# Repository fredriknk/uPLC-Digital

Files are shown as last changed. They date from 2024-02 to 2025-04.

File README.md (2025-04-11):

# μPLC-Digital
### Pcbway Sponsorship
Thanks so much to [PCBWay](https://www.pcbway.com/) who offered to assemble my first prototype batch of all three [uPLC modules](https://github.com/fredriknk/uPLC-stack). They deliver awesome quality as always, see the result for yourself below.

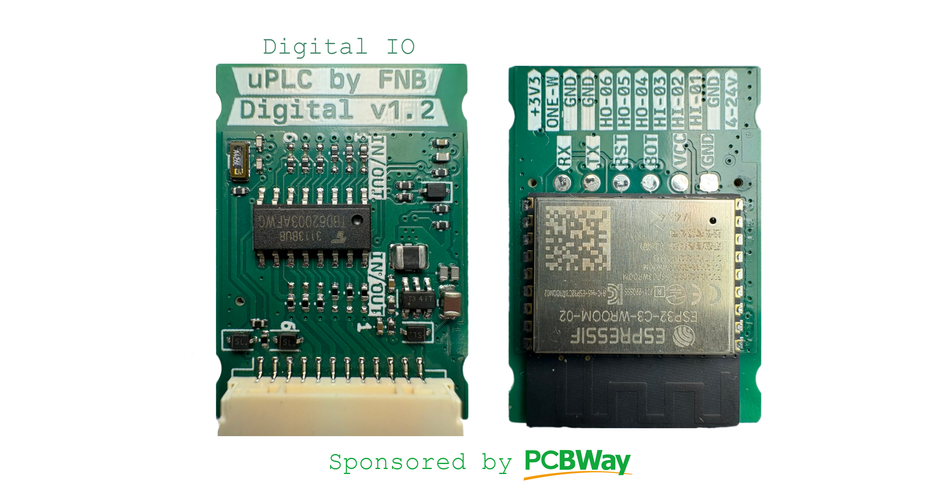
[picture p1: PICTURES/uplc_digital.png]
Front


 I now have two prototypes of the uPLC-Digital so ESP-Home integrations will come soon.

ESP micro PLC the size of a post stamp. 

The uPLC-digital version is an [ESP-32-C3](./DOCUMENTATION/esp-12f_product_specification_en.pdf) wifi, bluetooth module for communication and MCU, it has a 3.8-24V buck regulator, has three 2.5-25V inputs, three 2.5-25v 100ma high speed open drain outputs through a [TBD062003](./DOCUMENTATION/Transistor-array-2304140030_TOSHIBA-TBD62003AFWG_C114084.pdf) DMOS transistor array ic. And one protected 3.3v GPIO for onwire communication (Eg for DS18b20 sensors). The digital version allso has input voltage monitoring for battery applications. 

The HO HI ports can be configured to be inputs or outputs by jumping solder bridges one each side of the IC. By default 1-3 are outputs and 4-6 are inputs. 

[Schematic](./DOCUMENTATION/_schematic.pdf)

[Assembly IBOM](https://htmlpreview.github.io/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)

## Specifications
| **Parameter** | **Description** |
|---|---|
| _Input voltage_ | 3.8-24v |
| _Current_ | TBD Wifi: ##mA, Radio Off: ##mA, Deep sleep ##uA |  
| _Communication_ | 2.4ghz WIFI, Uart TTL |
| _Baudrate_ | 115200 |
| _PCB size_ | 21x31.4mm |
| _PCB info_ | 1.6mm FR4, HASL lead free, 4 layer |
| _Case size_ | XxXxXmm TBD |

## FIRST PRODUCTION PROTOTYPE
TODO

## Connector

| **Label** | **GPIO**|**Description** |
|---|-----|---|
|_3V3_ | 3V3 | 3.3v output for sensor connection |
|_ONE-W_ | GPIO18  | Protected gpio for onewire comm |
|_GND_ | GND | GND port for sensor connection|
|_GND_ | GND | GND port for sensor connection |
|_HO-06_ | GPIO10  | 25v 100ma open drain output |
|_HO-05_ | GPIO19  | 25v 100ma open drain output |
|_HO-04_ | GPIO3  | 25v 100ma open drain output |
|_HI-03_ | GPIO7  | 2.5-25v input (with pulldown) |
|_HI-02_ | GPIO6  | 2.5-25v input (with pulldown) |
|_HI-01_ | GPIO5  | 2.5-25v input (with pulldown) |
|_GND_ | GND |  Ground  |
|_4-24V_ | Buck reg |3.8-24v polarity protected input |

## PCB Pictures
PCB assembly by [PCBWay](https://www.pcbway.com/)
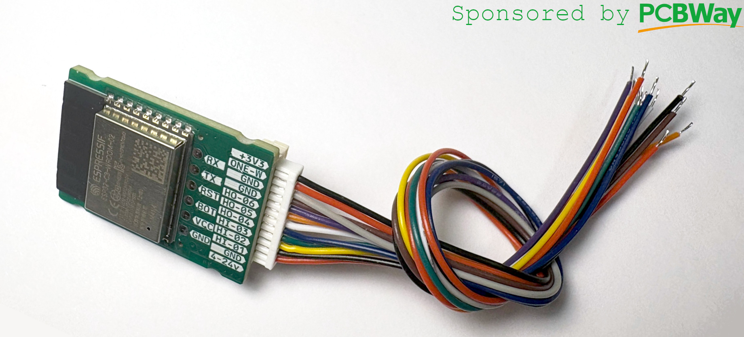
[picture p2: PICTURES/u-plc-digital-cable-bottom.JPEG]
Cable1

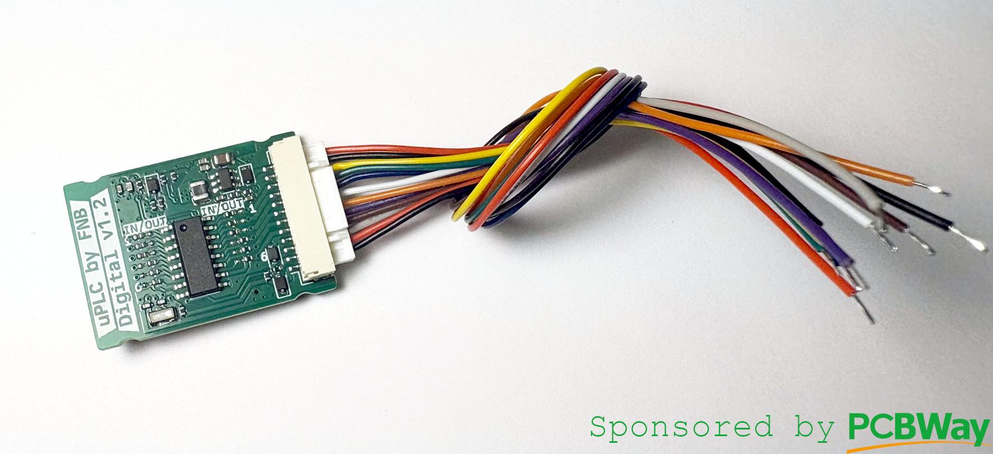
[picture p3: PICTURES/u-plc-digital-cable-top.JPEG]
Cable2

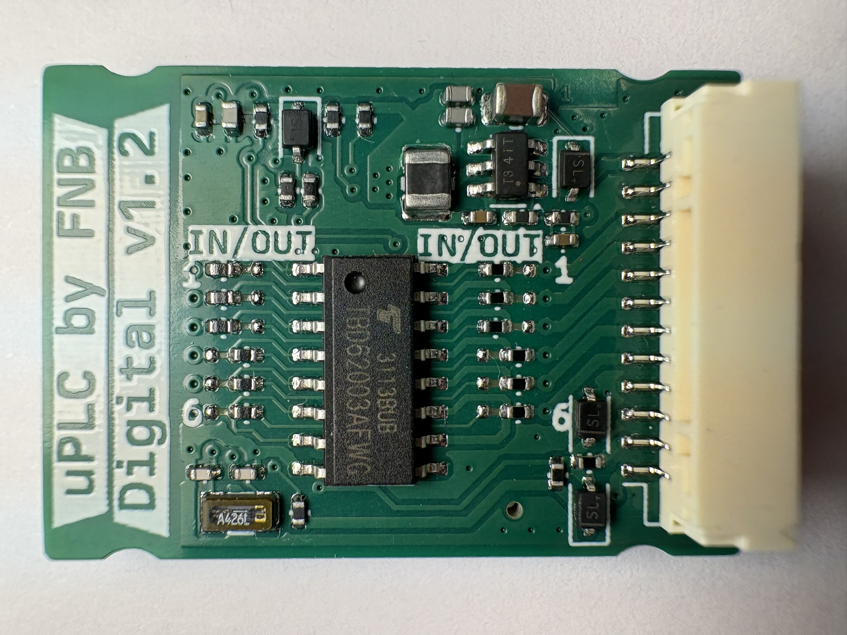
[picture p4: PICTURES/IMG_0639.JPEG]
Top

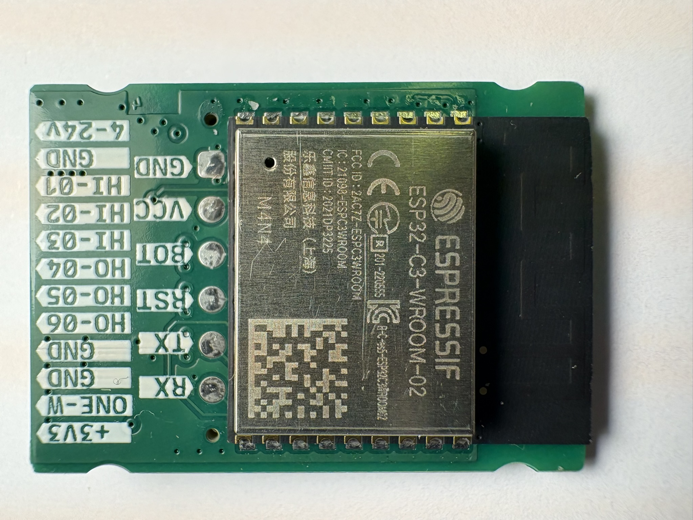
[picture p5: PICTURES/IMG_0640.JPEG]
Bottom


## Homeassistant Implementation
TODO

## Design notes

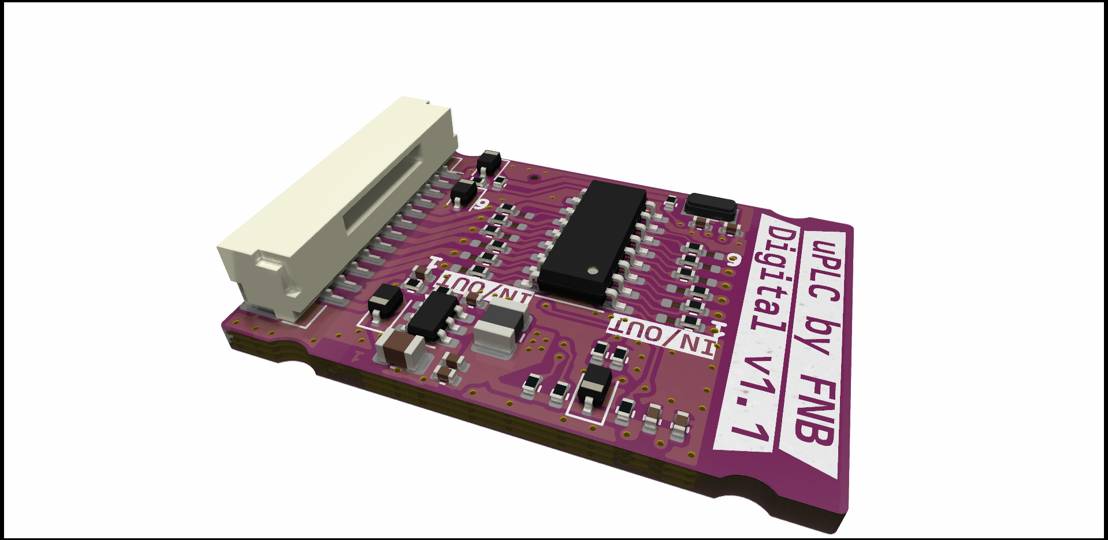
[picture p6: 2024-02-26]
PICTURES/TOP.PNG

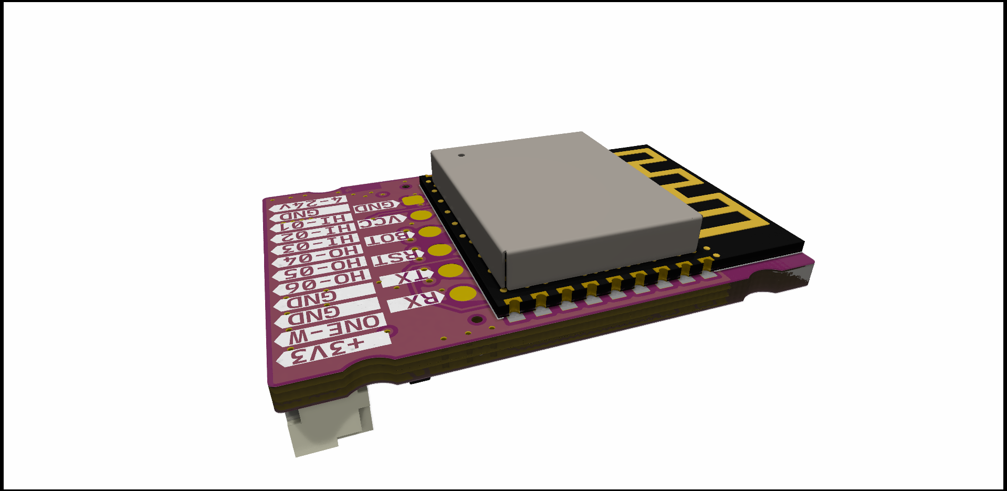
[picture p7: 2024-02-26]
PICTURES/BOTTOM.PNG

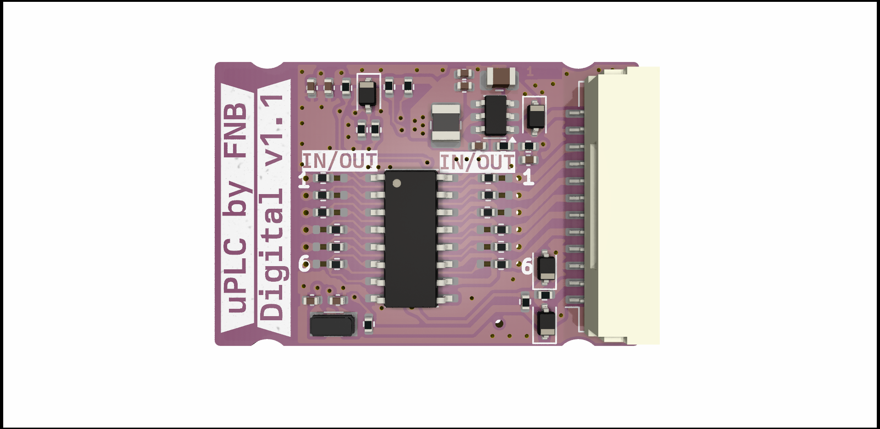
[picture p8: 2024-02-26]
PICTURES/OTOP.PNG

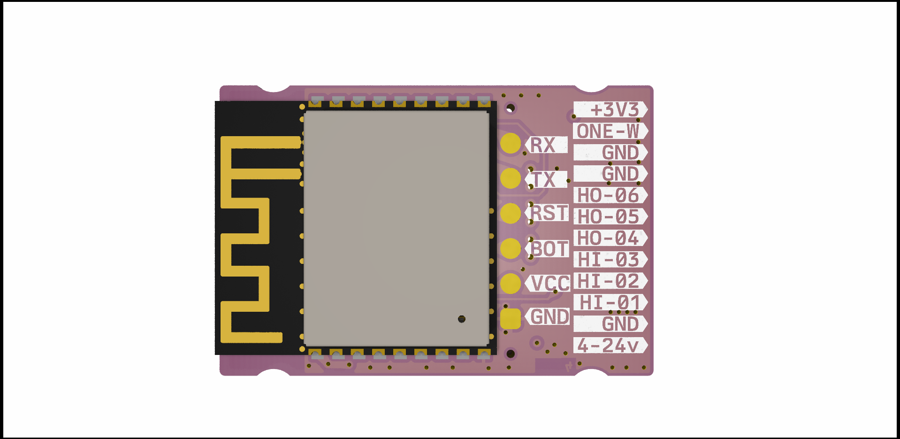
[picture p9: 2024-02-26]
PICTURES/OBOT.PNG

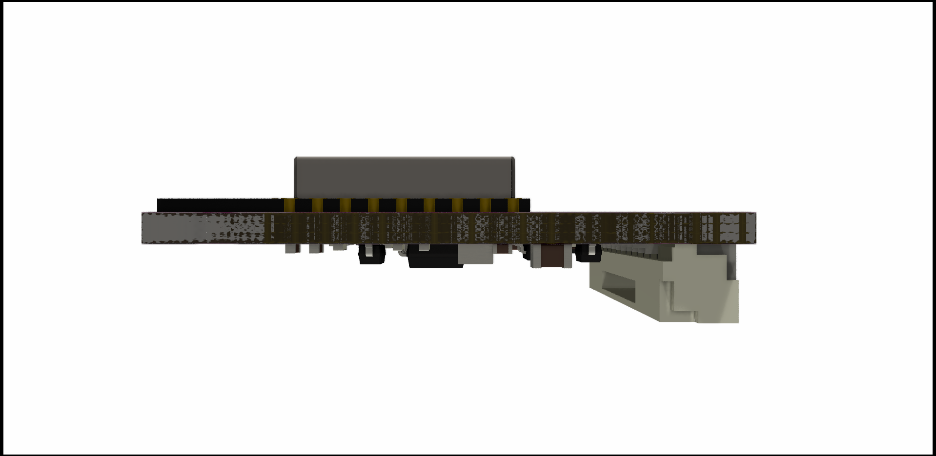
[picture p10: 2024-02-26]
PICTURES/OLEFT.png

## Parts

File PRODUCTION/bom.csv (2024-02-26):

Designator | Footprint | Quantity | Value | LCSC Part #
C1, C4 | 0402 | 2 | 20pf | C1554
C11, C12, C8 | 0402 | 3 | 22uf | C415703
C2, C3, C9 | 0402 | 3 | 0.1uF | C307331
C5 | 0805 | 1 | 10uF | C162422
D1, D2, D3, D4 | D_SOD-323 | 4 | 1N5819WS | C191023
J1 | TestPoint_Pad_1.0x1.0mm_6pad | 1 | Conn_01x06_Pin | DNP
J2 | JST_GH_SM12B-GHS-TB_1x12-1MP_P1.25mm_Horizontal | 1 | SM12B-GHS-TB(LF)(SN) | C265421
JP1, JP10, JP11, JP12, JP2, JP3, JP4, JP5, JP6, JP7, JP8, JP9 | SolderJumper-3_P1.3mm_BridgedSMD12_0402 | 12 | 0R
L1 | 1008 | 1 | 6.8uH | C98340
R1, R2, R3, R4, R5, R6 | 0402 | 6 | 10K | C25744
R13 | 0402 | 1 | 100R | C25076
R14 | 0402 | 1 | 182k | C11481
R15 | 0402 | 1 | 62k | C137950
R7 | 0402 | 1 | 309k
U1 | TSOT-23-6 | 1 | AP63201WU | C2071044
U2 | SOIC-16_3.9x9.9mm_P1.27mm | 1 | TBD62003AFWG | C114084
U3 | ESP32-C3-WROOM-02 | 1 | ESP32-C3-WROOM-02 | C2934560
Y1 | Crystal_SMD_3215-2Pin_3.2x1.5mm | 1 | 32.768khz 3215 12.5pf | C32346

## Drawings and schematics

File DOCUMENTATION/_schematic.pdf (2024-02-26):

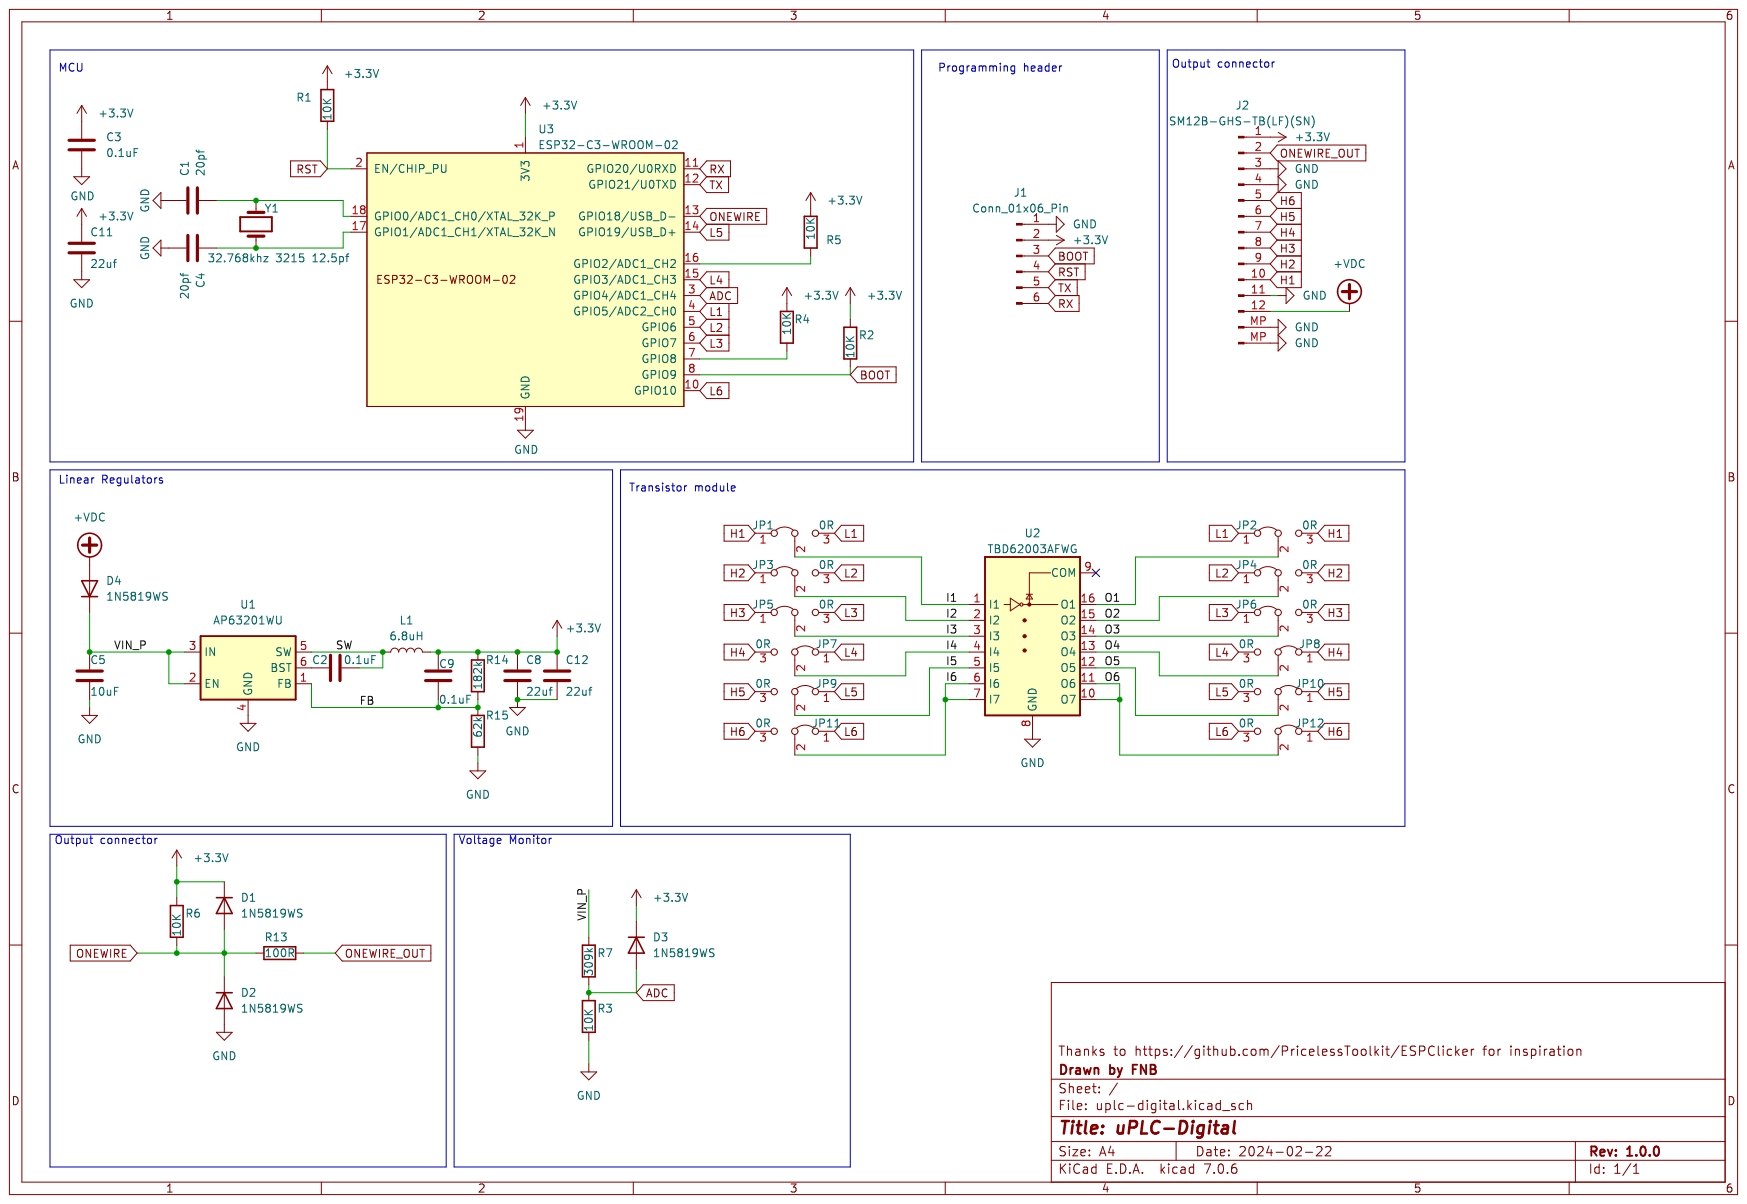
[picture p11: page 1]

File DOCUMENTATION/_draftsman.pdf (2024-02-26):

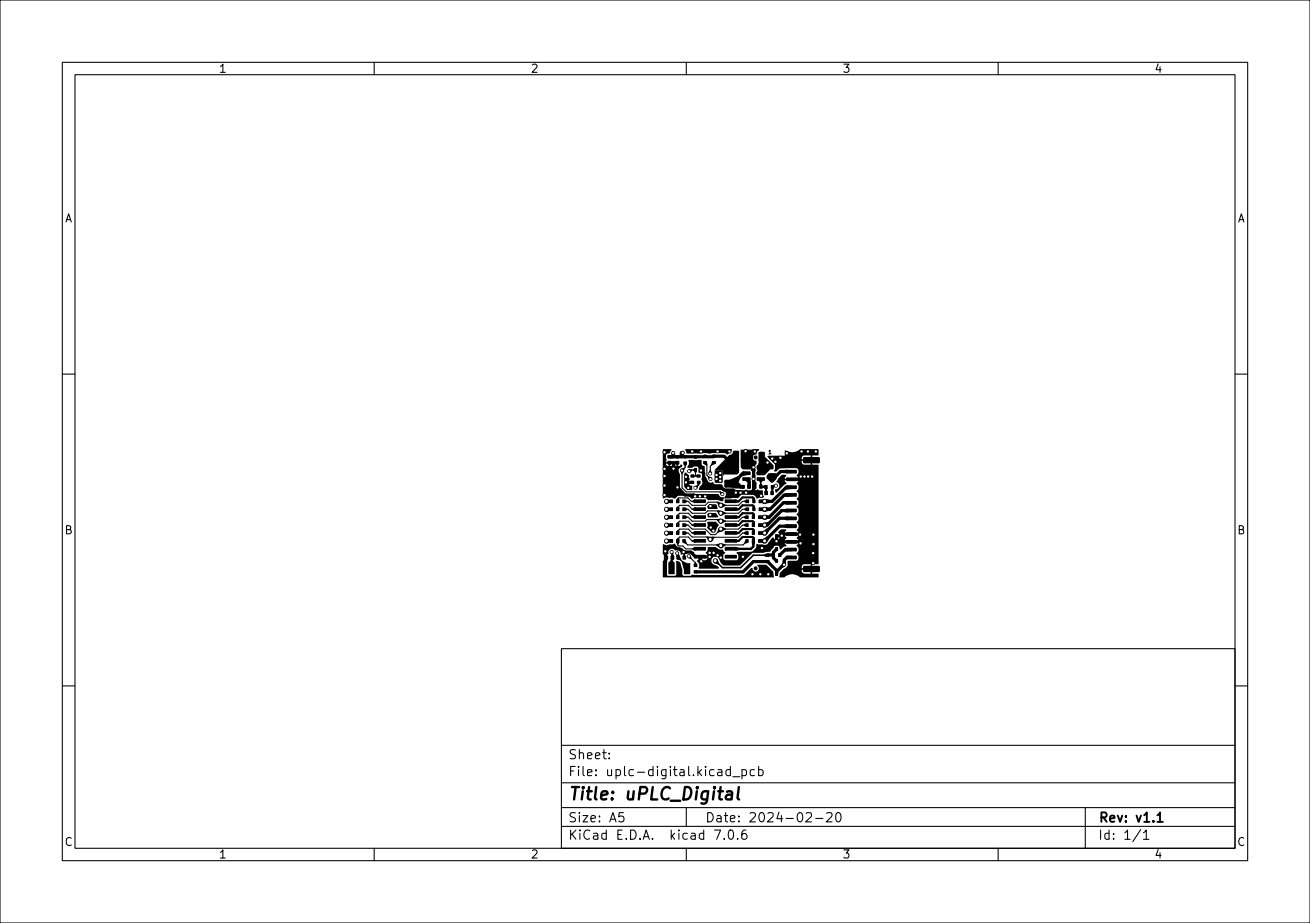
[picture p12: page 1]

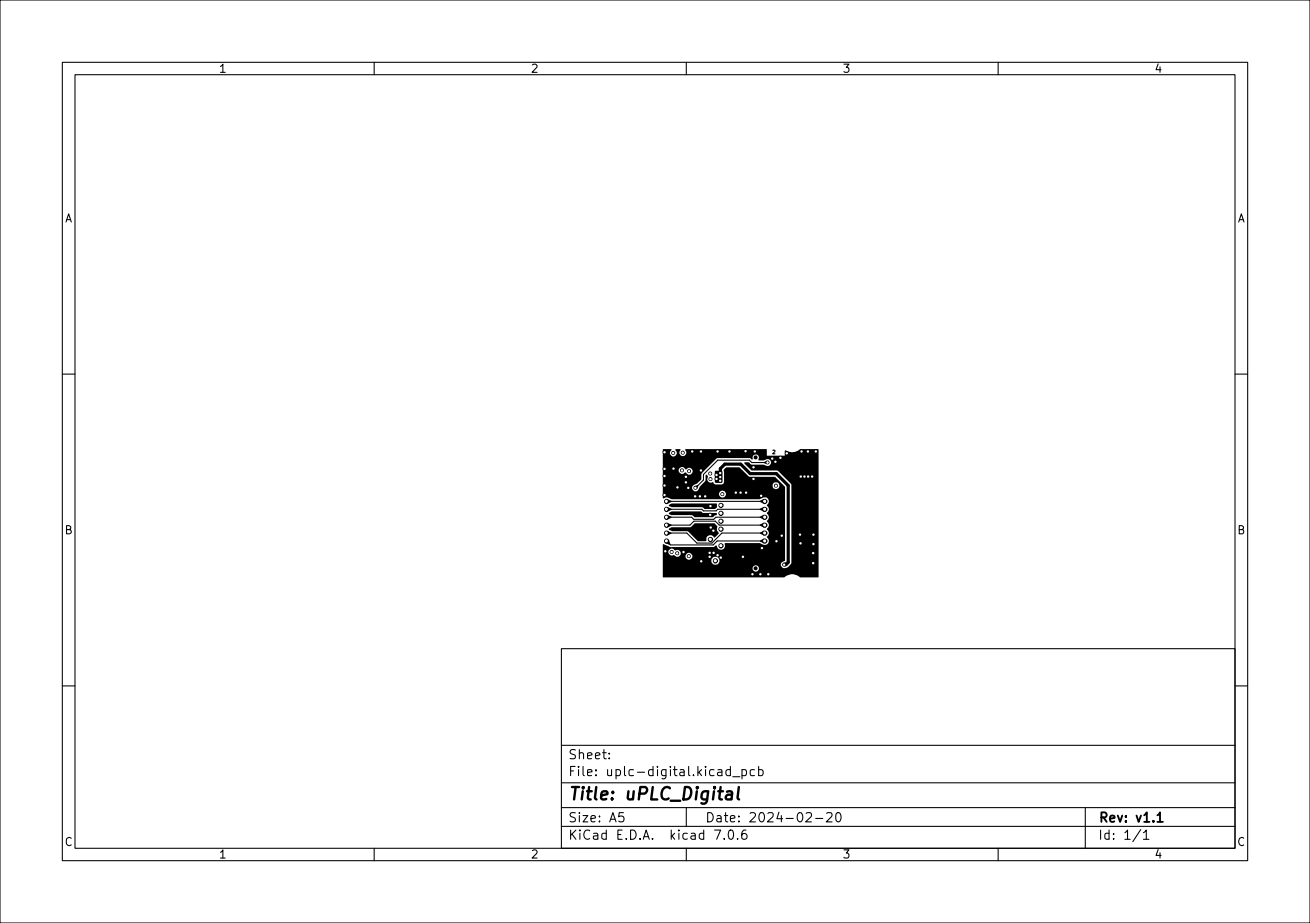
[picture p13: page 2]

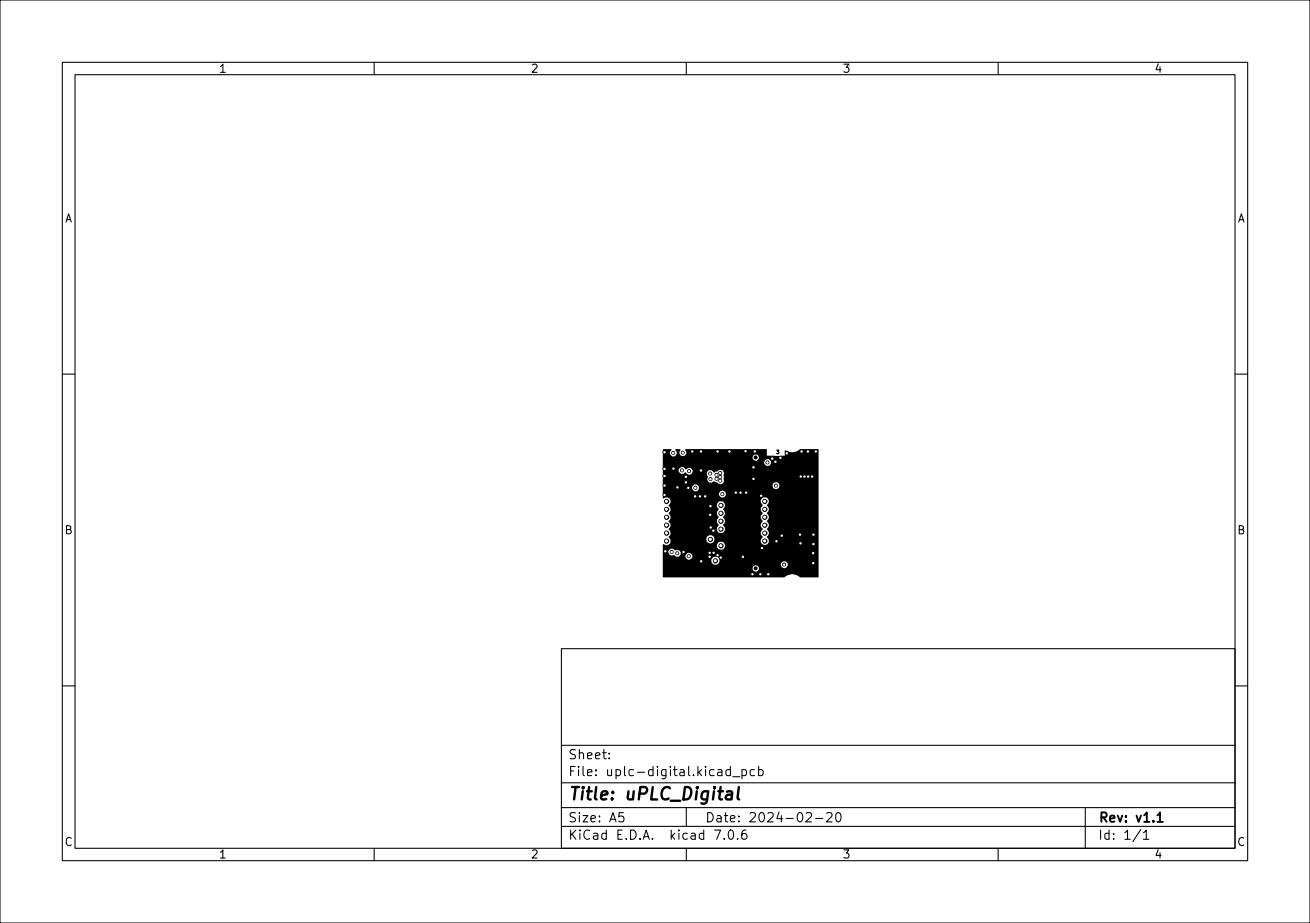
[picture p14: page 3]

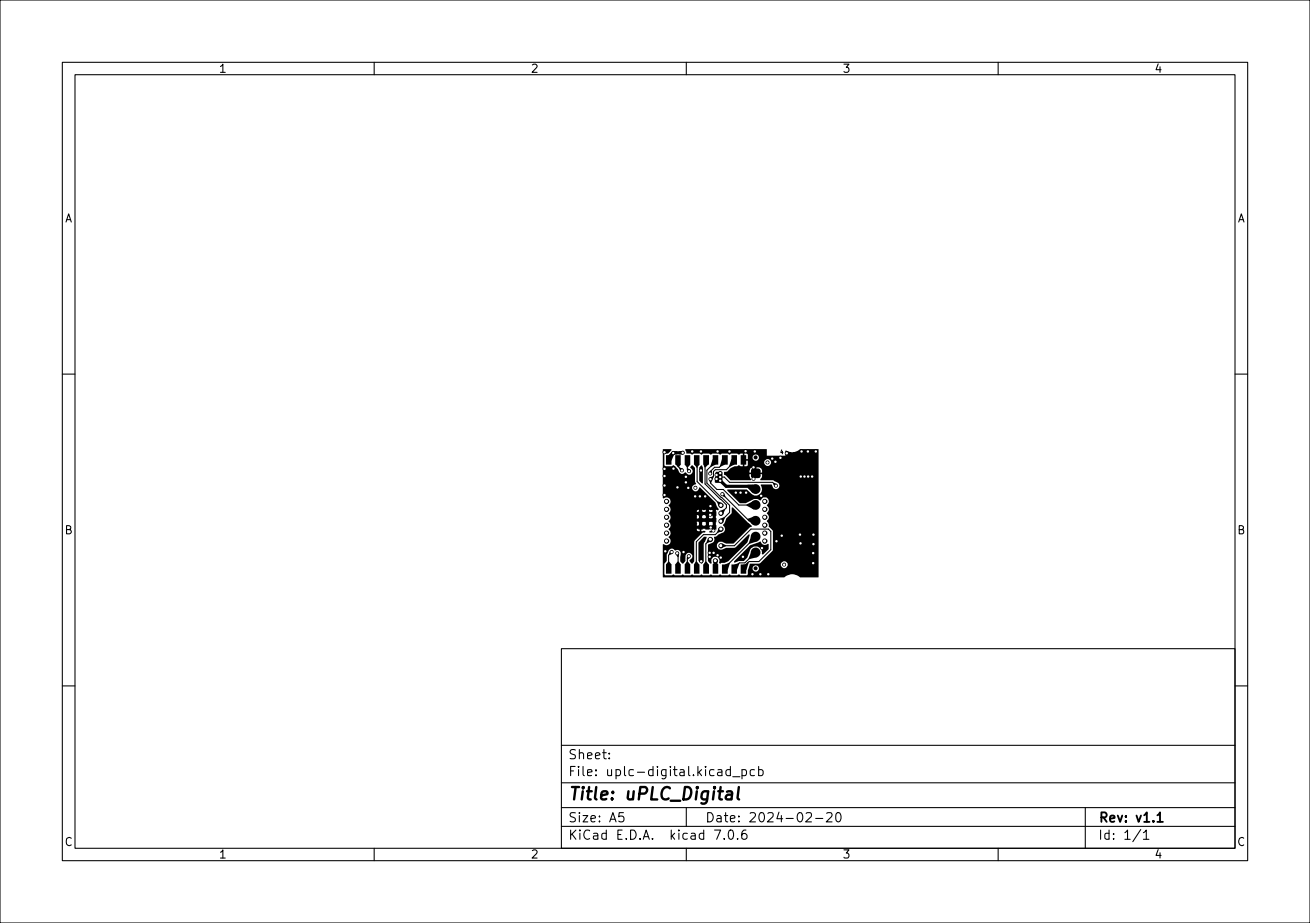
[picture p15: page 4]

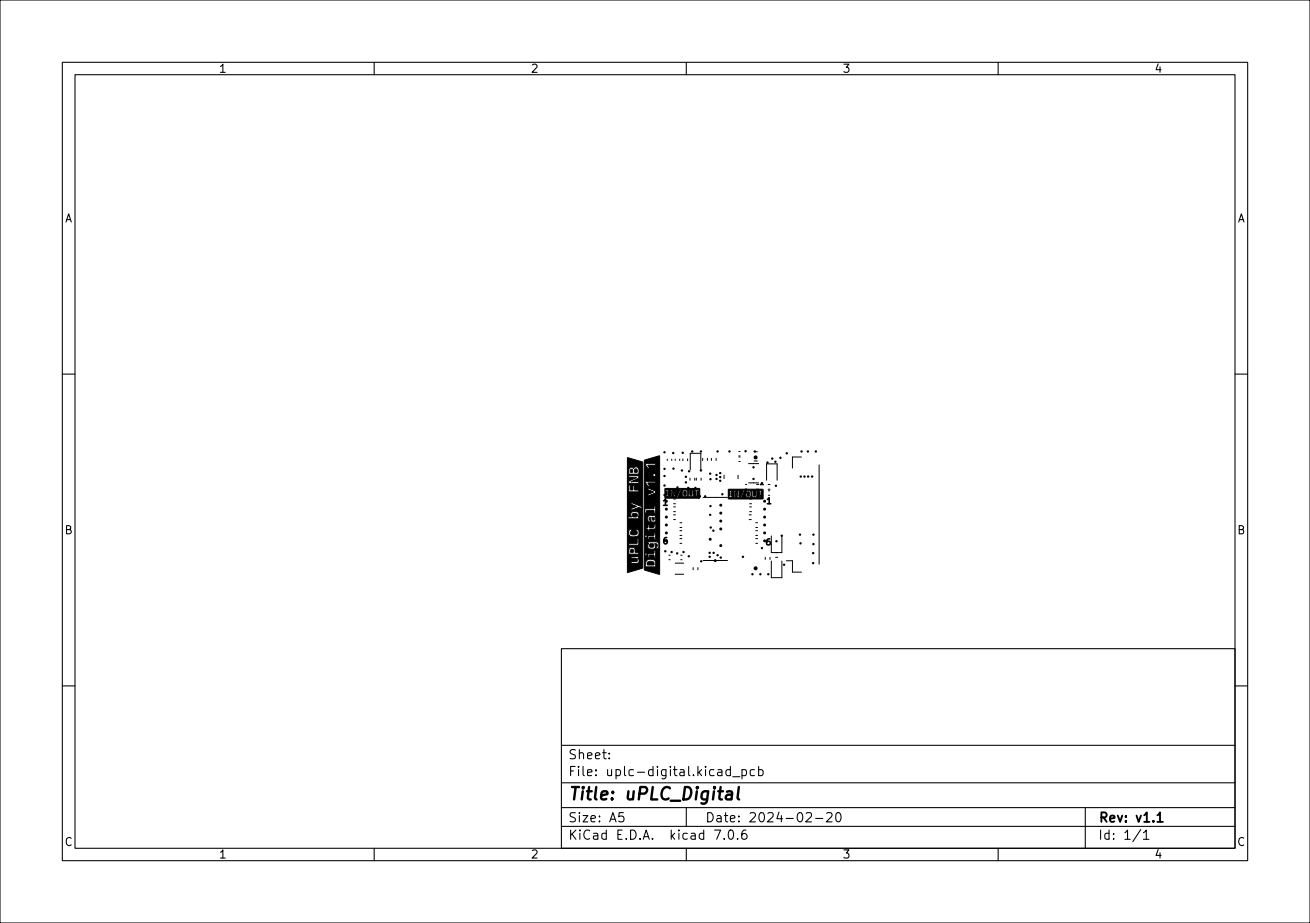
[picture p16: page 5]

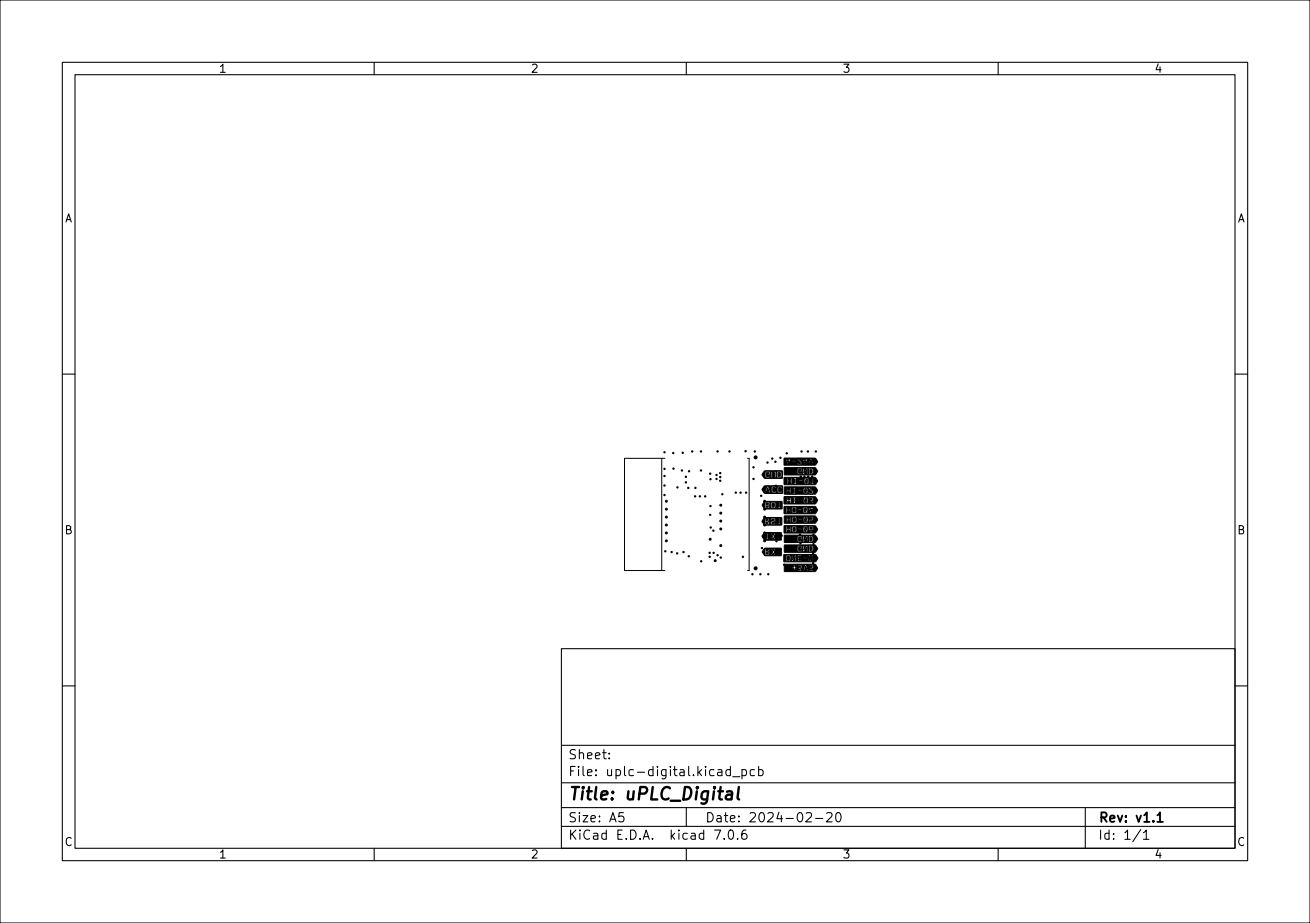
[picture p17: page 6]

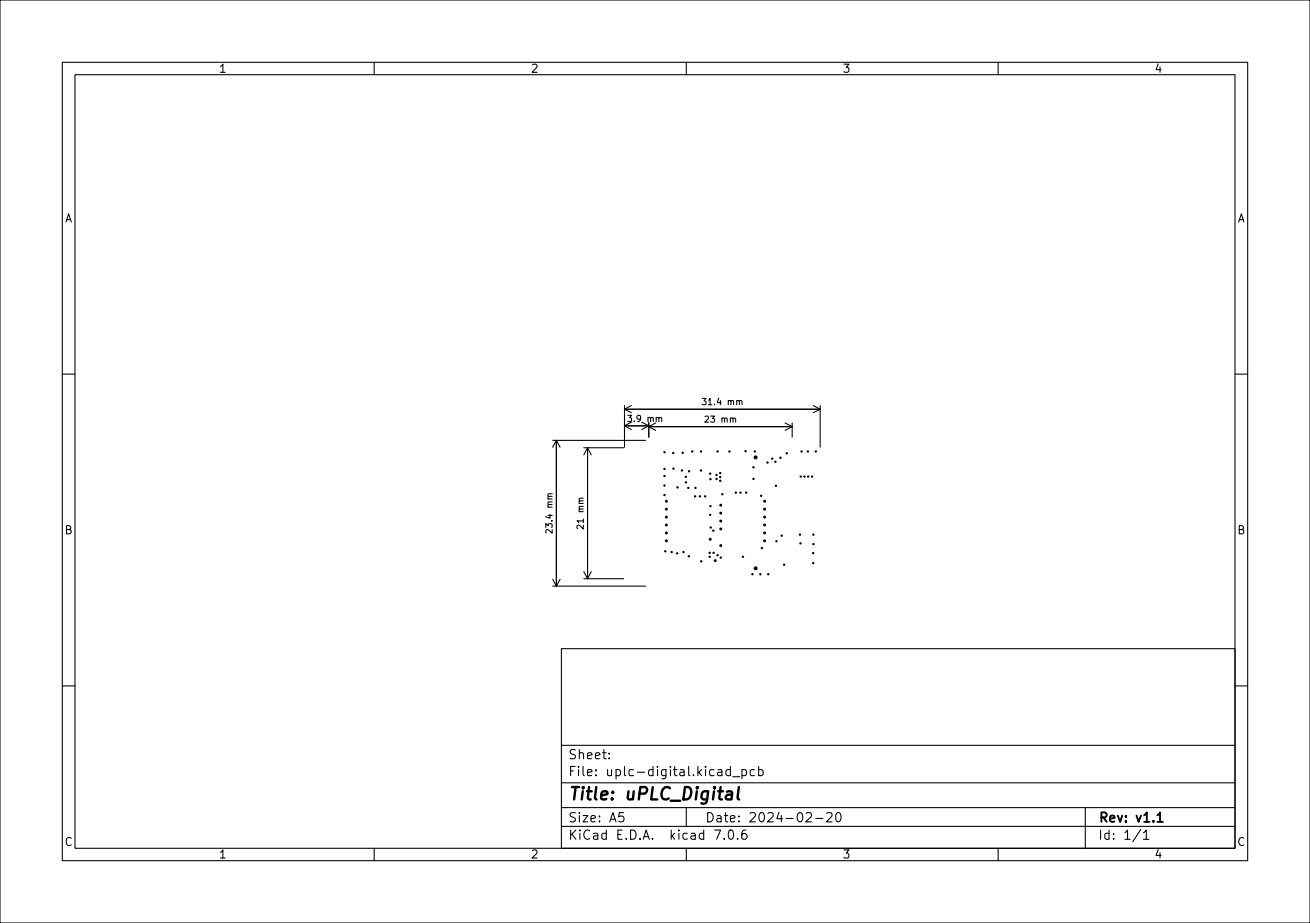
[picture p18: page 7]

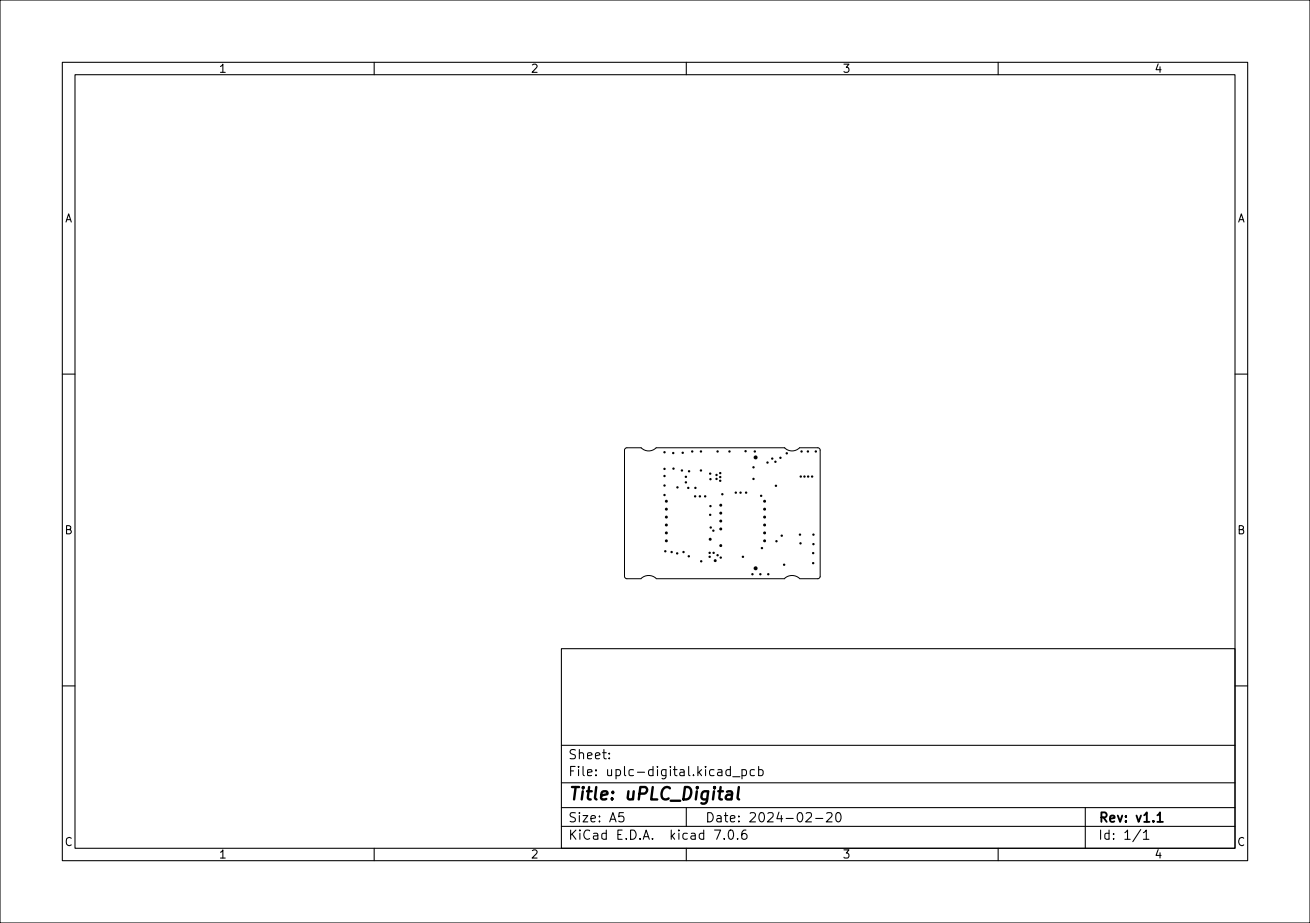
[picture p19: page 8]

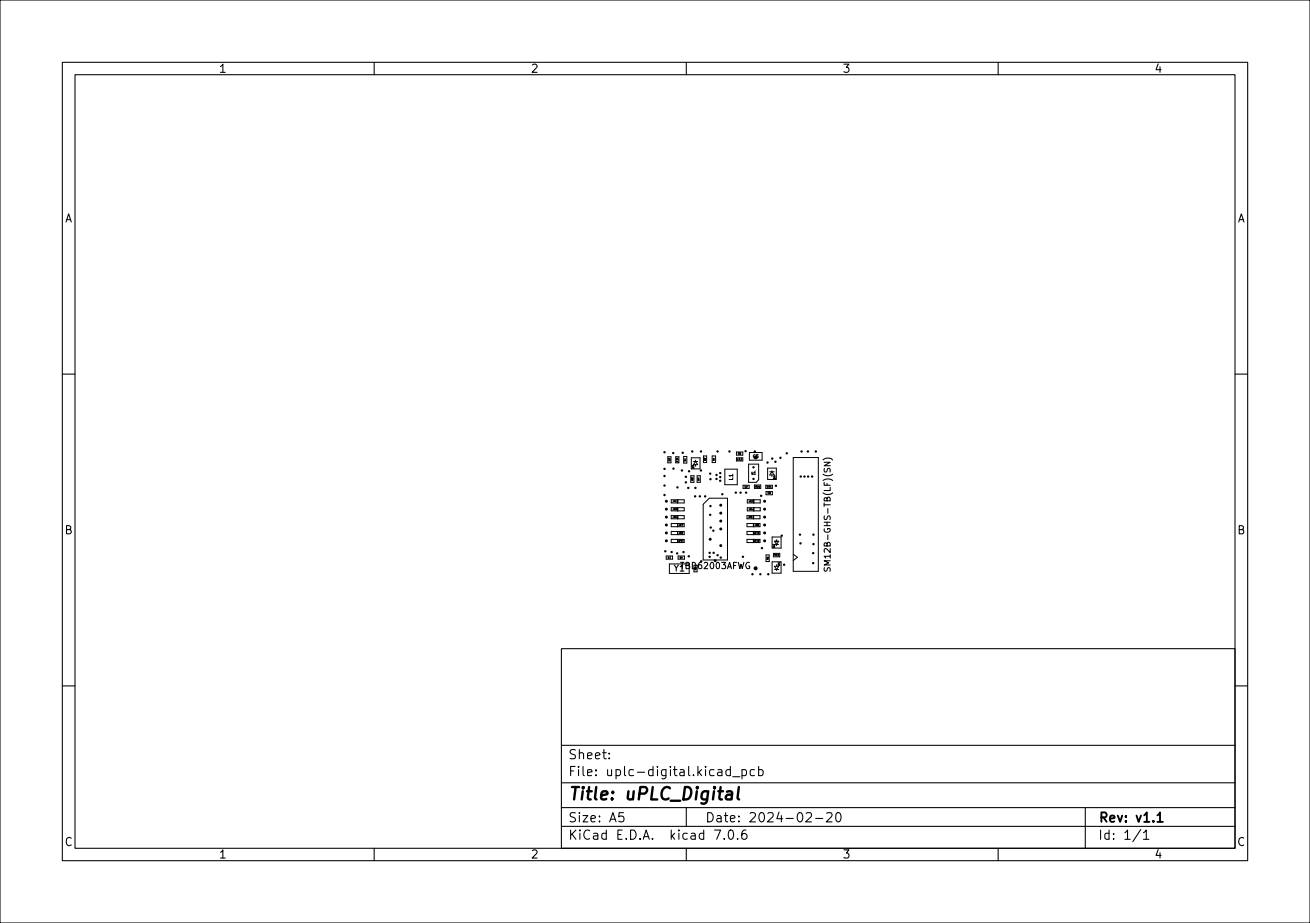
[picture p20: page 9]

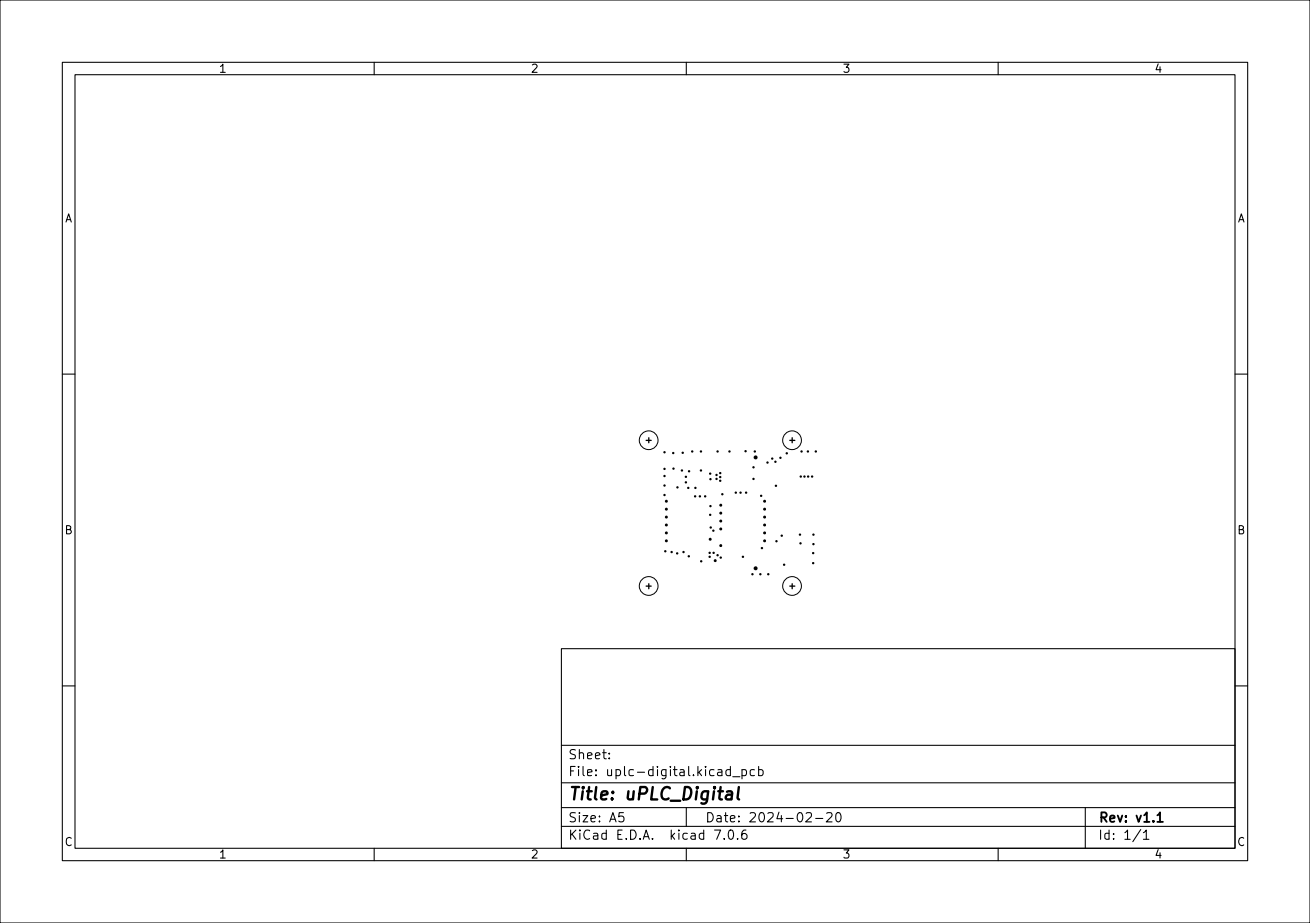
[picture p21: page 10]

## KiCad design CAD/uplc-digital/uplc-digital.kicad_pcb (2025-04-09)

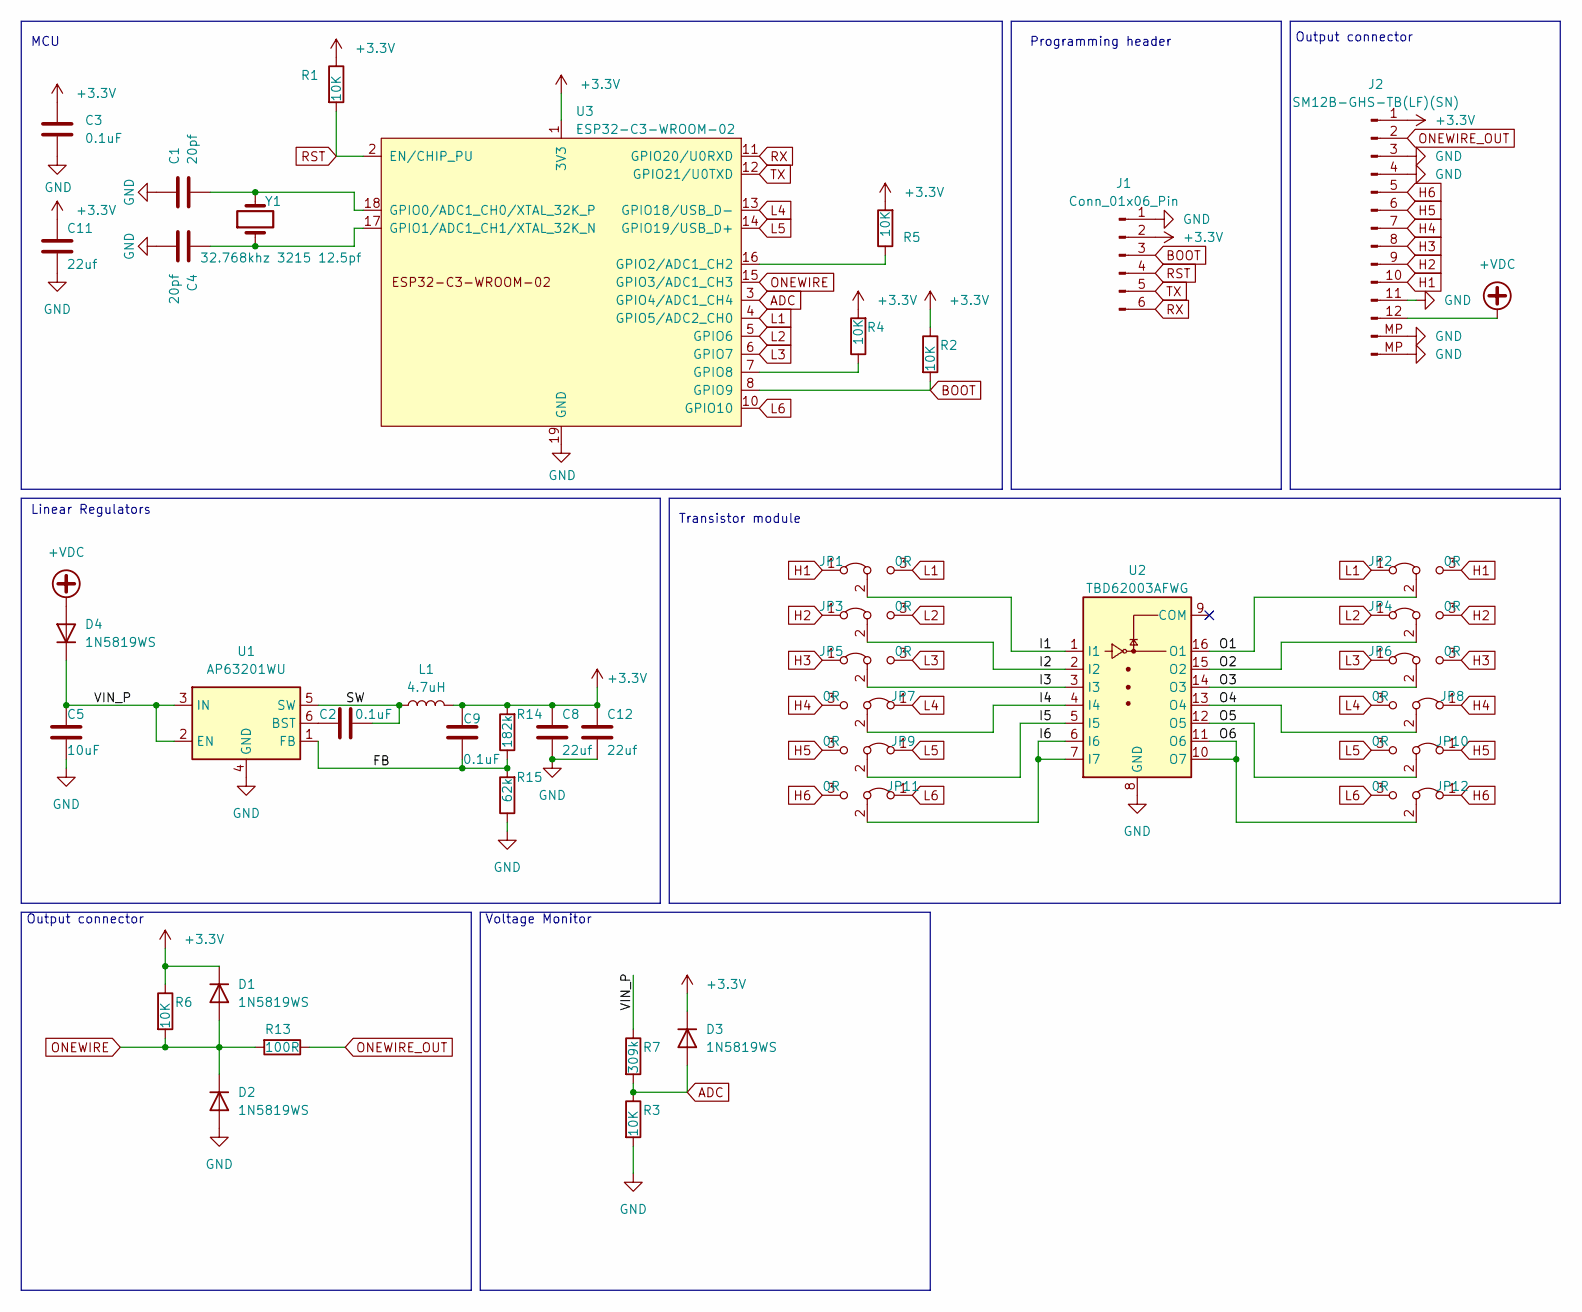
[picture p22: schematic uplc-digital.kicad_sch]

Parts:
C1, C4: 20pf; C_0402_1005Metric; MPN 0402CG200J500NT; LCSC Part # C1554
C2, C3, C9: 0.1uF; C_0402_1005Metric; MPN GRM155R71H104KE14D; LCSC Part # C77020
C5: 10uF; C_0805_2012Metric; MPN GRM21BR6YA106KE43L; LCSC Part # C162422
C8, C11, C12: 22uf; C_0402_1005Metric; MPN GRM155R60J226ME11D; LCSC Part # C415703
D1, D2, D3, D4: 1N5819WS; D_SOD-323; MPN 1N5819WS; LCSC Part # C191023
J1: Conn_01x06_Pin; TestPoint_Pad_1.0x1.0mm_6pad; LCSC Part # DNP
J2: SM12B-GHS-TB(LF)(SN); JST_GH_SM12B-GHS-TB_1x12-1MP_P1.25mm_Horizontal; MPN SM12B-GHS-TB(LF)(SN); LCSC Part # C265421
JP1, JP2, JP3, JP4, JP5, JP6, JP7, JP8, JP9, JP10, JP11, JP12: 0R; SolderJumper-3_P1.3mm_BridgedSMD12_0402; MPN RTT02000JTH; LCSC Part # C102746
L1: 4.7uH; L_1008_2520Metric; MPN LQM2HPN4R7MG0L; LCSC Part # C82314
R1, R2, R3, R4, R5, R6: 10K; R_0402_1005Metric; MPN 0402WGF1002TCE; LCSC Part # C25744
R7: 309k; R_0402_1005Metric; MPN RTT023093FTH; LCSC Part # C159040
R13: 100R; R_0402_1005Metric; MPN 0402WGF1000TCE; LCSC Part # C25076
R14: 182k; R_0402_1005Metric; MPN 0402WGF1823TCE; LCSC Part # C11481
R15: 62k; R_0402_1005Metric; MPN RC0402FR-0762KL; LCSC Part # C137950
U1: AP63201WU; TSOT-23-6; MPN AP63201WU-7; LCSC Part # C2071044
U2: TBD62003AFWG; SOIC-16_3.9x9.9mm_P1.27mm; MPN TBD62003AFWG; LCSC Part # C114084
U3: ESP32-C3-WROOM-02; MPN ESP32-C3-WROOM-02-N4; LCSC Part # C2934560
Y1: 32.768khz 3215 12.5pf; Crystal_SMD_3215-2Pin_3.2x1.5mm; MPN Q13FC13500004; LCSC Part # C32346

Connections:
+3.3V: C3.1, C8.1, C9.1, C11.1, C12.1, D1.1 (K), D3.1 (K), J1.2, J2.1, L1.2, R1.1, R2.1, R4.2, R5.2, R6.1, R14.2, U3.1 (3V3)
+VDC: D4.2 (A), J2.12
/FB: C9.2, R14.1, R15.2, U1.1 (FB)
/I1: JP1.2 (C), U2.1 (I1)
/I2: JP3.2 (C), U2.2 (I2)
/I3: JP5.2 (C), U2.3 (I3)
/I4: JP7.2 (C), U2.4 (I4)
/I5: JP9.2 (C), U2.5 (I5)
/I6: JP11.2 (C), U2.6 (I6), U2.7 (I7)
/O1: JP2.2 (C), U2.16 (O1)
/O2: JP4.2 (C), U2.15 (O2)
/O3: JP6.2 (C), U2.14 (O3)
/O4: JP8.2 (C), U2.13 (O4)
/O5: JP10.2 (C), U2.12 (O5)
/O6: JP12.2 (C), U2.10 (O7), U2.11 (O6)
/SW: C2.1, L1.1, U1.5 (SW)
/VIN_P: C5.1, D4.1 (K), R7.1, U1.2 (EN), U1.3 (IN)
ADC: D3.2 (A), R3.1, R7.2, U3.3 (GPIO4/ADC1_CH4)
BOOT: J1.3, R2.2, U3.8 (GPIO9)
GND: C1.1, C3.2, C4.2, C5.2, C8.2, C11.2, C12.2, D2.2 (A), J1.1, J2.3, J2.4, J2.11, J2.MP (Pin_13), R3.2, R15.1, U1.4 (GND), U2.8 (GND), U3.9 (GND), U3.19 (GND)
H1: J2.10, JP1.1 (A), JP2.3 (B)
H2: J2.9, JP3.1 (A), JP4.3 (B)
H3: J2.8, JP5.1 (A), JP6.3 (B)
H4: J2.7, JP7.3 (B), JP8.1 (A)
H5: J2.6, JP9.3 (B), JP10.1 (A)
H6: J2.5, JP11.3 (B), JP12.1 (A)
L1: JP1.3 (B), JP2.1 (A), U3.4 (GPIO5/ADC2_CH0)
L2: JP3.3 (B), JP4.1 (A), U3.5 (GPIO6)
L3: JP5.3 (B), JP6.1 (A), U3.6 (GPIO7)
L4: JP7.1 (A), JP8.3 (B), U3.13 (GPIO18/USB_D-)
L5: JP9.1 (A), JP10.3 (B), U3.14 (GPIO19/USB_D+)
L6: JP11.1 (A), JP12.3 (B), U3.10 (GPIO10)
unnamed: C2.2, U1.6 (BST)
unnamed: C1.2, U3.18 (GPIO0/ADC1_CH0/XTAL_32K_P), Y1.2
unnamed: C4.1, U3.17 (GPIO1/ADC1_CH1/XTAL_32K_N), Y1.1
unnamed: R5.1, U3.16 (GPIO2/ADC1_CH2)
unnamed: R4.1, U3.7 (GPIO8)
ONEWIRE: D1.2 (A), D2.1 (K), R6.2, R13.2, U3.15 (GPIO3/ADC1_CH3)
ONEWIRE_OUT: J2.2, R13.1
RST: J1.4, R1.2, U3.2 (EN/CHIP_PU)
RX: J1.6, U3.11 (GPIO20/U0RXD)
TX: J1.5, U3.12 (GPIO21/U0TXD)

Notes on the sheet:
Transistor module
Linear Regulators
MCU
Output connector
Programming header
Voltage Monitor

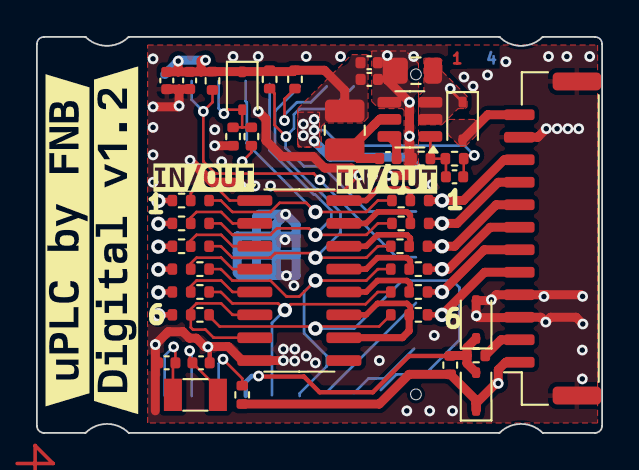
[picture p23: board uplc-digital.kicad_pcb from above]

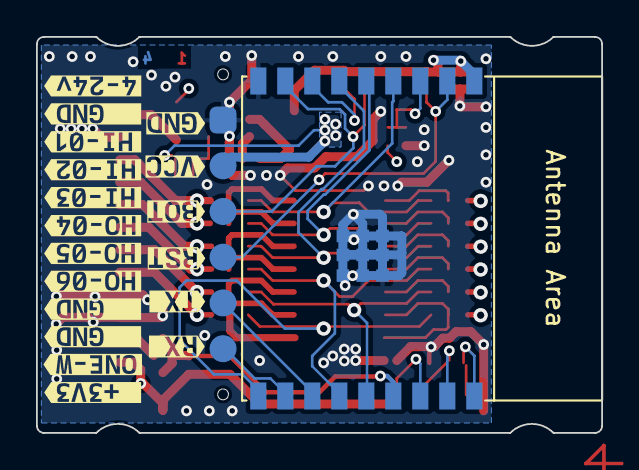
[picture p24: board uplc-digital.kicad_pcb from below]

Board: 4 copper layers, 31.4 x 22.0 mm, 64 parts (20 on the bottom side), 42 nets.

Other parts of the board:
kibuzzard-65D8B0E2: G***; kibuzzard-65D8B0E2
kibuzzard-65D8B0ED: G***; kibuzzard-65D8B0ED
kibuzzard-65D8B0F8: G***; kibuzzard-65D8B0F8
kibuzzard-65D8B10C: G***; kibuzzard-65D8B10C
kibuzzard-65D8B28C: G***; kibuzzard-65D8B28C
kibuzzard-65D8B104: G***; kibuzzard-65D8B104
kibuzzard-65D8B121: G***; kibuzzard-65D8B121
kibuzzard-65D8B297: G***; kibuzzard-65D8B297
kibuzzard-65D8B343: G***; kibuzzard-65D8B343
kibuzzard-65D74DE1: G***; kibuzzard-65D74DE1
kibuzzard-65D74DEE: G***; kibuzzard-65D74DEE
kibuzzard-65D74DFB: G***; kibuzzard-65D74DFB
kibuzzard-65D460A0: G***; kibuzzard-65D460A0
kibuzzard-65D3616E: G***; kibuzzard-65D3616E
kibuzzard-65D7176D: G***; kibuzzard-65D7176D
kibuzzard-65D7177B: G***; kibuzzard-65D7177B
kibuzzard-65D36177: G***; kibuzzard-65D36177
kibuzzard-65D46022: G***; kibuzzard-65D46022
kibuzzard-65D46066: G***; kibuzzard-65D46066
kibuzzard-65D49092: G***; kibuzzard-65D49092
kibuzzard-65D71774: G***; kibuzzard-65D71774
kibuzzard-65DCA831: G***; kibuzzard-65DCA831

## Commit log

2024-02-22 Fork uplc
    [bom.csv, designators.csv, positions.csv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]
2024-02-22 Rev 1.0
    [bom.csv, designators.csv, positions.csv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]
2024-02-23 WIP rev 1.1
    [uplc-digital.kicad_pcb, uplc-digital.kicad_sch]
2024-02-23 Rev 1.1 Schem PCB done
    [uplc-digital.kicad_pcb, uplc-digital.kicad_sch, uplc.kicad_pcb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]
2024-02-26 Rev 1.1 Push for production
    [bom.csv, designators.csv, positions.csv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]
2024-02-26 Rev 1.2
    [uplc-digital.kicad_pcb, uplc-digital.kicad_sch]
2024-10-14 Panelization changes
    [uplc-digital.kicad_pcb, uplc-digital.kicad_sch]
2025-04-09 Feat: V1.1
    [bom.csv, designators.csv, positions.csv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]
